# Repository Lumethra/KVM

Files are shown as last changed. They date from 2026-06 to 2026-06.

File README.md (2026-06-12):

# KVM
## What is this?

Its a KVM, just there is a catch, it should be a KM, because it doesnt fulfill the criterias for the "V". A KVM is a device that can let you switch the connected USB-devices from one PC to another, so just press or toggle the switch and your mouse and keyboard are connected to the other device, for example a laptop. KVM stands for Keyboard, Video, Mouse and since my thingi only supports USB-devices it only supports keyboards, mice and maybe other usb devices. Thats also why I would call it a KM. 

### Features:
  - 2 USB-C-upstreams
      - for the 2 PC's
  - 4 USB-downstreams
      - 2 USB-C
      - 2 USB-A
  - 1 SL2.1S to bundle the 4 downstreams into 2 pins (D+, D-)
  - 1 Mux to switch between the 2 upstreams for PC switching
  - 1 slider, toggle, switch kinda thingi to set the state

---

## Why?

I thought it would be funny to try that out. It turned out to be quite easy. I also thought about USB3.0 and even USB4.0, but that was too complicated and I settled on USB2.0. A KVM is also sth that you can use in your daily workflow and could turn out to be really handy. 

---

## How??

It was simply replicating the USB-Hub, which I made for my keebs and connecting the upstream to the mux which handles the switching between the 2 USB-C(2.0) to archieve the switching between devices. 

---

## Renders 
> enjoy the raytracing

| PCB with Components | 
| --- |
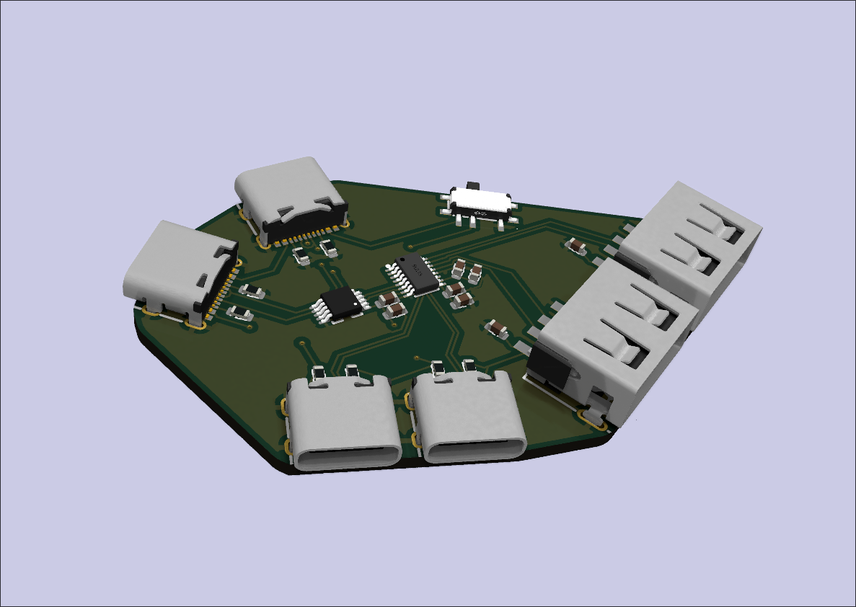
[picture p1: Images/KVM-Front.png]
KVM Front with Components
|  |
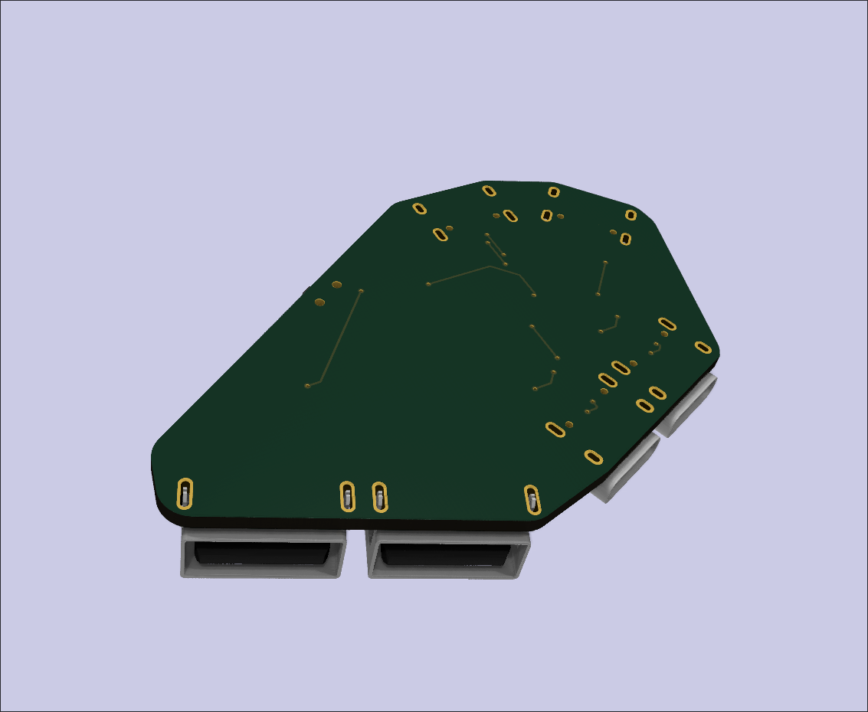
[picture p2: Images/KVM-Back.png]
KVM Back with Components
|  |

| PCB without Components |
| --- |
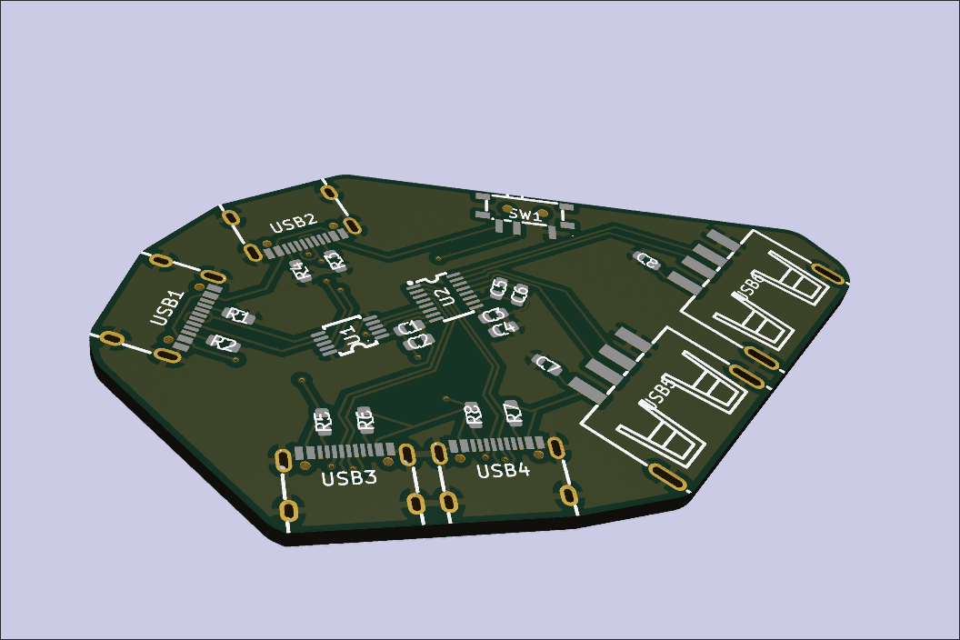
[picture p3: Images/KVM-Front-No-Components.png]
KVM Front without Components
|  |
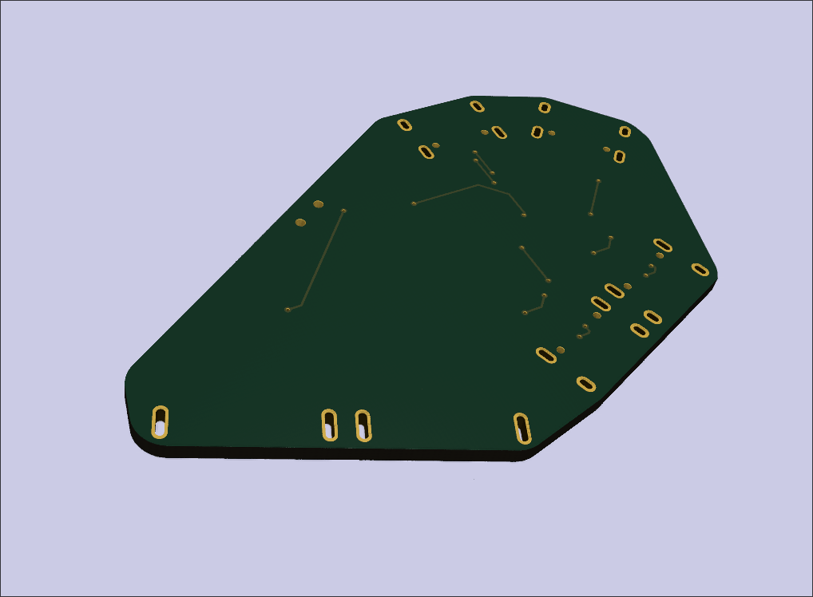
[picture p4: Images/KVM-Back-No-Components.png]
KVM Back without Compoenents
|  |

---

## PCB + Schematics

| Schematics |
| --- |
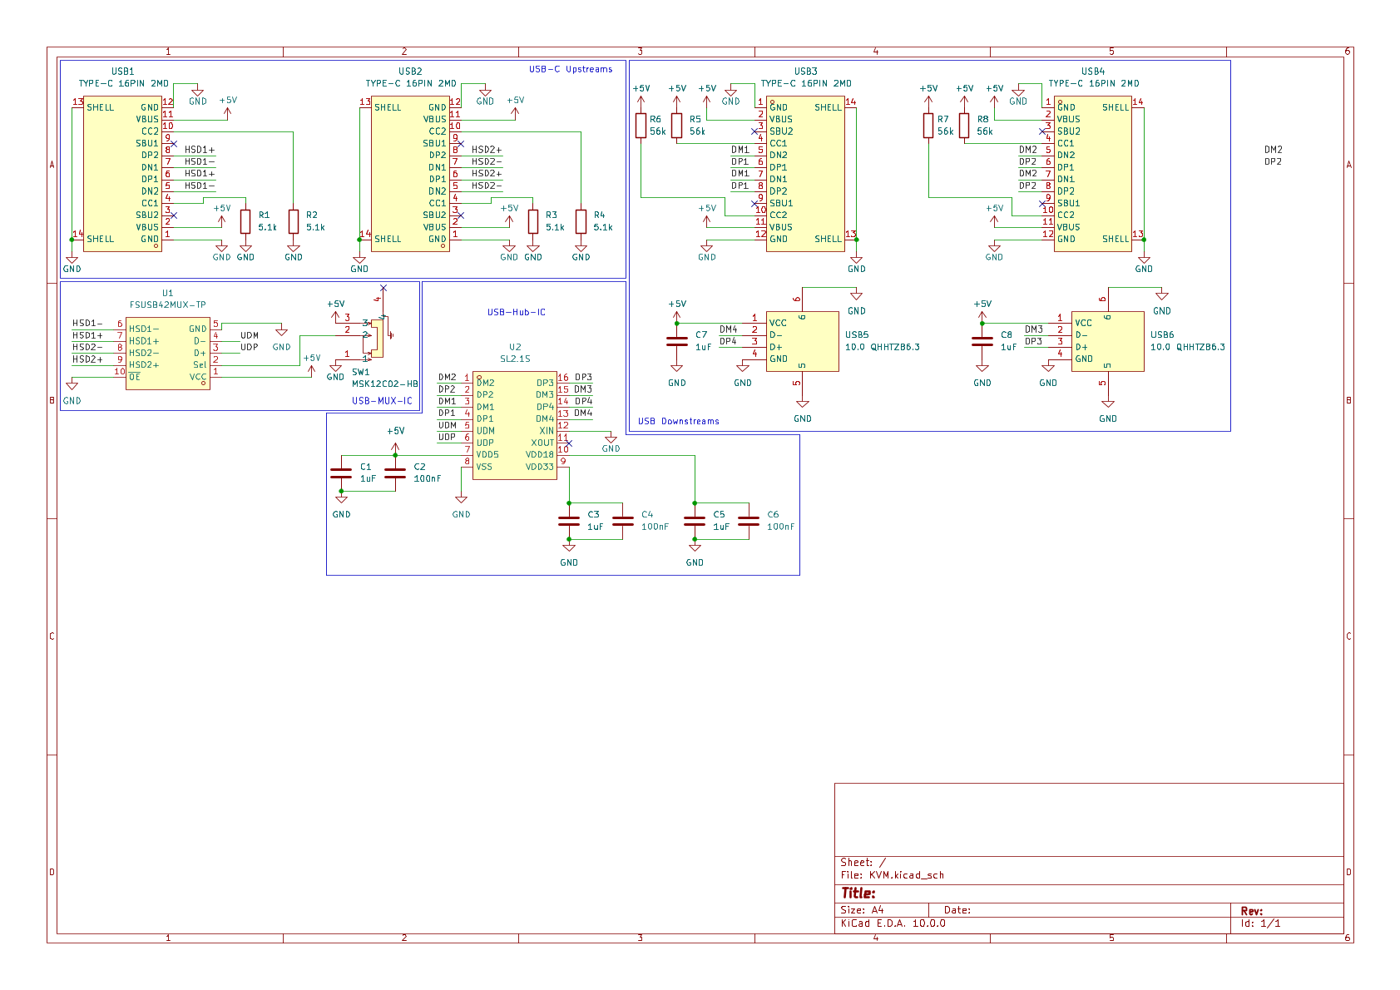
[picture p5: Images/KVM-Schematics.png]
KVM-PCB
|  |

| PCB |
| --- |
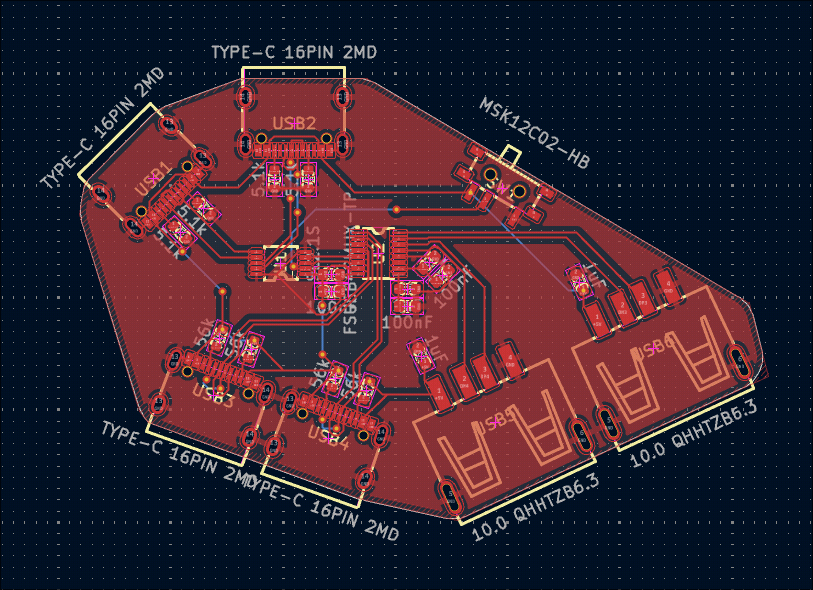
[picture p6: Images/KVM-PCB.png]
KVM-Schematics
|  |

---

<details>
  <summary>
    <h2>Zine</h2>
  </summary>

| Zine |
| --- |
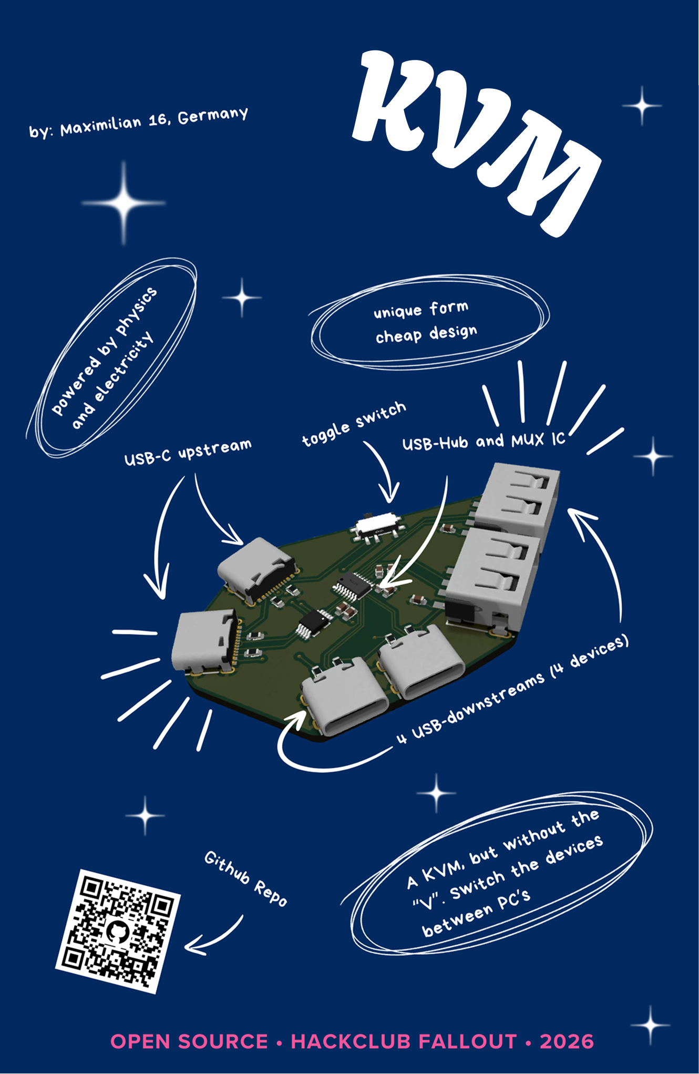
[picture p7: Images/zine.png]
KVM-Zine
|  |

  ---
</details>

## BOM

| Part | Purpose | Cost | Quantity | Total Cost | LCSC/JLCPCB Number | Link |
| --- | --- | --- | --- | --- | --- | --- |
| PCB |connect everything together | $2 | 1(5) | $2 | ~ | [JLCPCB](https://jlcpcb.com) |
| Capacitors | reduce noise in the power | $0.0032 | 8 | $0.0256 | C15849, C14663 | [C15849](https://jlcpcb.com/partdetail/C15849) / [C14663](https://jlcpcb.com/partdetail/C14663) |
| Resistors | prevent things go boom | $0.0016 | 8 | $0.0138 | C23186, C23206 | [C23186](https://jlcpcb.com/partdetail/C23186),[C23206](https://jlcpcb.com/partdetail/C23206) |
| Toggle Switch | say which computer | $0.0579 | 1 | $0.0579 | C431541 | [JLCPCB](https://jlcpcb.com/partdetail/C431541)  |
| USB Mux | change computer (USB) | $0.3720 | 1 | $0.3720 | C42407092 | [JLCPCB](https://jlcpcb.com/partdetail/C42407092)  |
| USB Hub | bundle the downstream | $0.2258 | 1 | $0.2258 | C2684433 | [JLCPCB](https://jlcpcb.com/partdetail/C2684433)  |
| UCB-C | usb connectors | $0.0740 | 4 | $0.2960 | C2765186 | [JLCPCB](https://jlcpcb.com/partdetail/C2765186)  |
| USB-A | usb connectors big | $0.0636 | 2 | $0.1272 | C668591 | [JLCPCB](https://jlcpcb.com/partdetail/C668591)  |

> the prices can change depending on the provider and time <br>
> you can find the JLCPCB parts on [LCSC](https://lcsc.com/) too (exept the PCB) <br>

---

## Contribute

Want to add something?? Want a real KVM with Video? Found any bugs?? Feel free to open a PR (pull request) or an issue. 
> the libraries are all imported with [easyeda2kicad](https://github.com/uPesy/easyeda2kicad.py)

---

## Thank you

A huge thank you to my brain, who didnt die in this session. Another huge thank you to all the guys teaching me hardware. A last thank you to my laptop and kicad who dont like each other and decides to crash alot.

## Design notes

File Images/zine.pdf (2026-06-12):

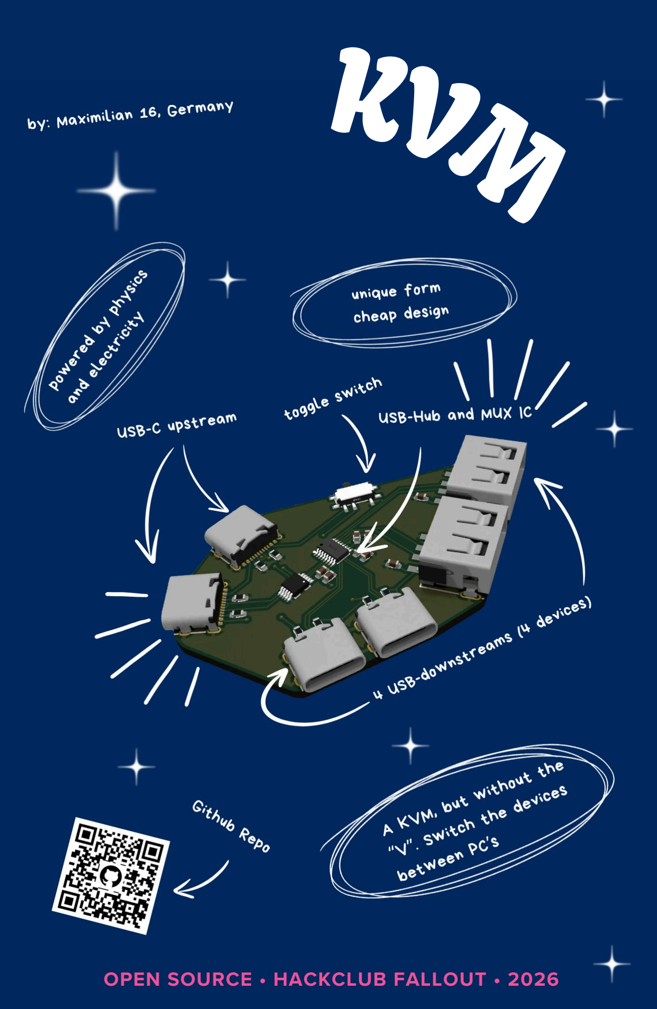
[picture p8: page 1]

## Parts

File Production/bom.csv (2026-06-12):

Name | Designator | Footprint | Quantity | Value | Price | LCSC Part # | Purchase Link
Capacitors 1uF | C1, C3, C5, C7, C8 | 0603 | 5 | 1uF | $0.0032 | C15849 | https://jlcpcb.com/partdetail/C15849
Capacitors 100nF | C2, C4, C6 | 0603 | 3 | 100nF | $0.0032 | C14663 | https://jlcpcb.com/partdetail/C14663
Resistors 5.1k | R1, R2, R3, R4 | 0603 | 4 | 5.1k | $0.0016 | C23186 | https://jlcpcb.com/partdetail/C23186
Resistors 56k | R5, R6, R7, R8 | 0603 | 4 | 56k | $0.0016 | C23206 | https://jlcpcb.com/partdetail/C23206
Toggle Switch | SW1 | SW-TH_MSK12C02-HB-1 | 1 | MSK12C02-HB | $0.0579 | C431541 | https://jlcpcb.com/partdetail/C431541
USB Mux | U1 | MSOP-10_L3.0-W3.0-P0.50-LS4.9-BL | 1 | FSUSB42MUX-TP | $0.3720 | C42407092 | https://jlcpcb.com/partdetail/C42407092
USB Hub | U2 | SSOP-16_L4.6-W2.6-P0.53-LS4.0-BL | 1 | SL2.1S | $0.2258 | C2684433 | https://jlcpcb.com/partdetail/C2684433
USB-C Connector | USB1, USB2, USB3, USB4 | USB-C-SMD_TYPE-C-6PIN-2MD-073 | 4 | TYPE-C 16PIN 2MD | $0.0740 | C2765186 | https://jlcpcb.com/partdetail/C2765186
USB-A Connector | USB5, USB6 | USB-A-TH_10.0QHHTZB6.3 | 2 | 10.0 QHHTZB6.3 | $0.0636 | C668591 | https://jlcpcb.com/partdetail/C668591

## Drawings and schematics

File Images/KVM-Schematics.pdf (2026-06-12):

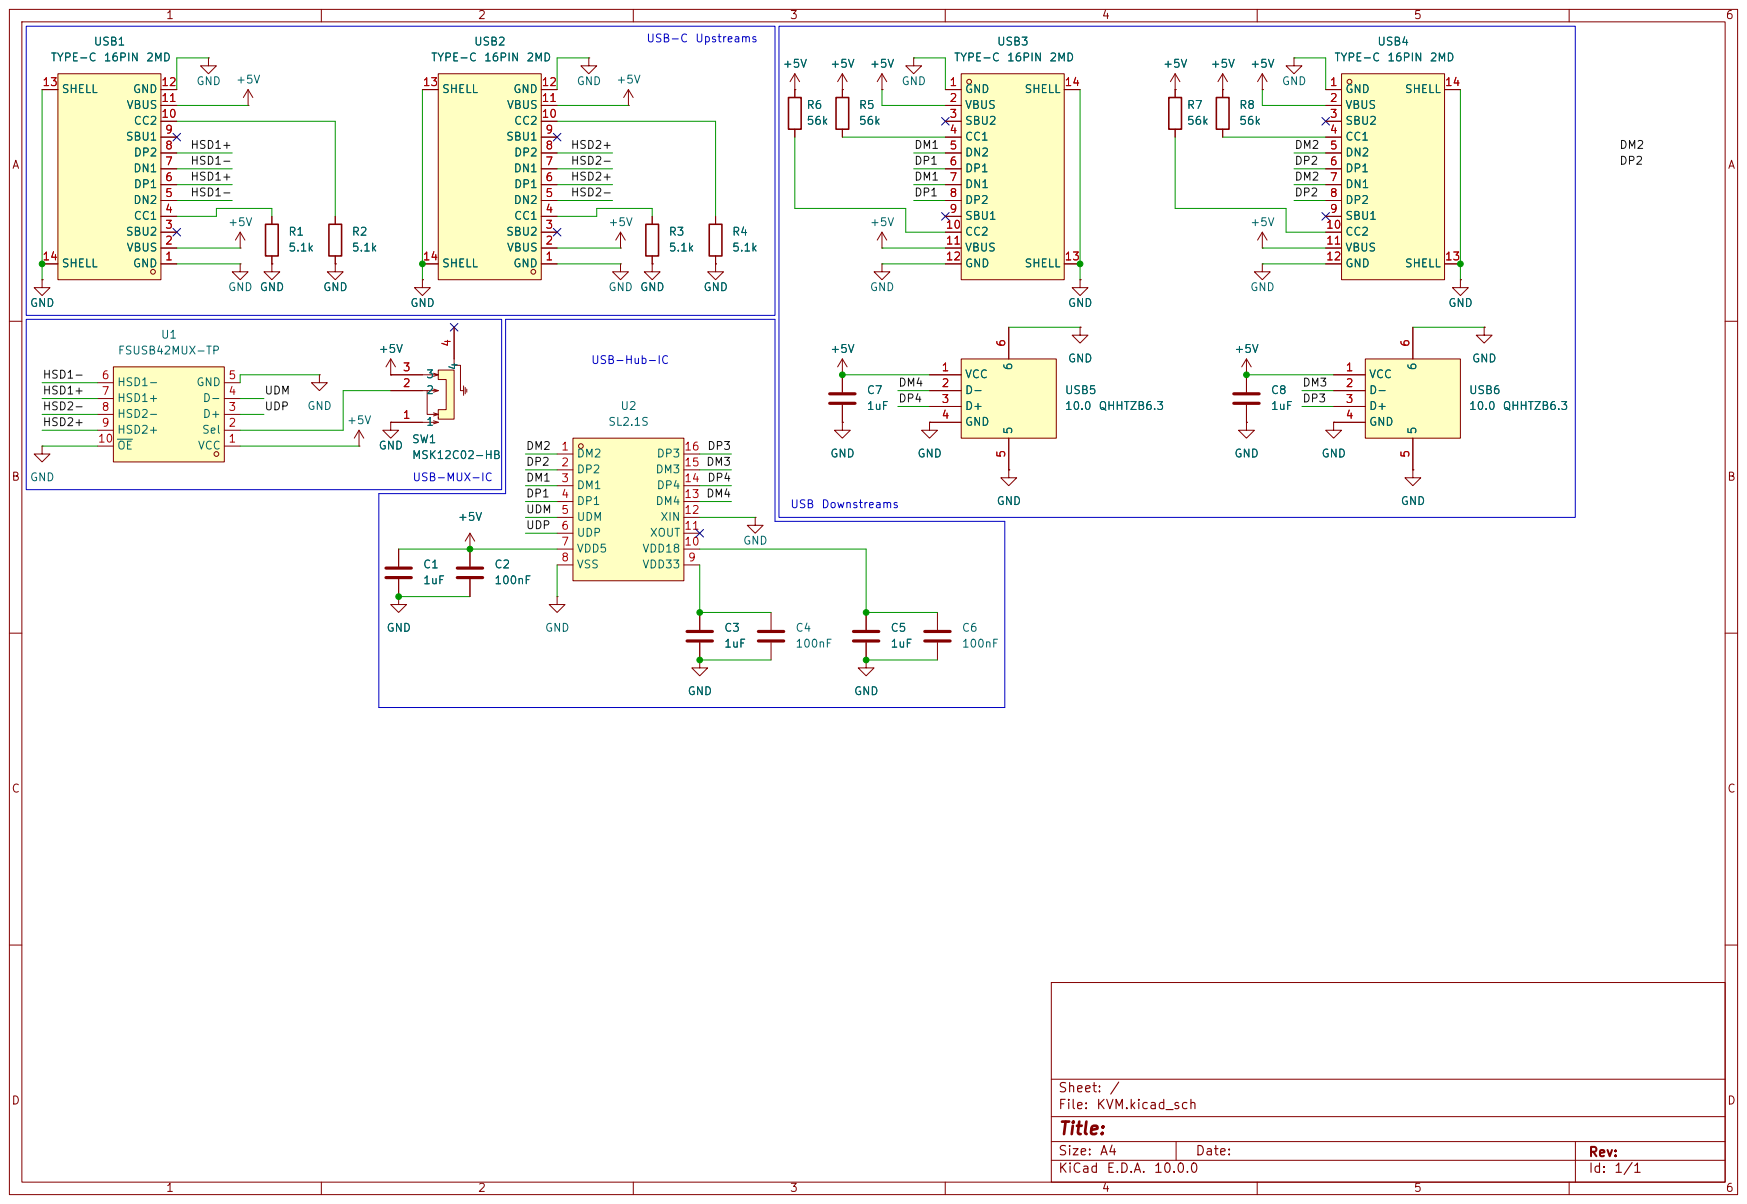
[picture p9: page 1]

Size: A4 | Rev:
KiCad E.D.A. 10.0.0 | Id: 1/1

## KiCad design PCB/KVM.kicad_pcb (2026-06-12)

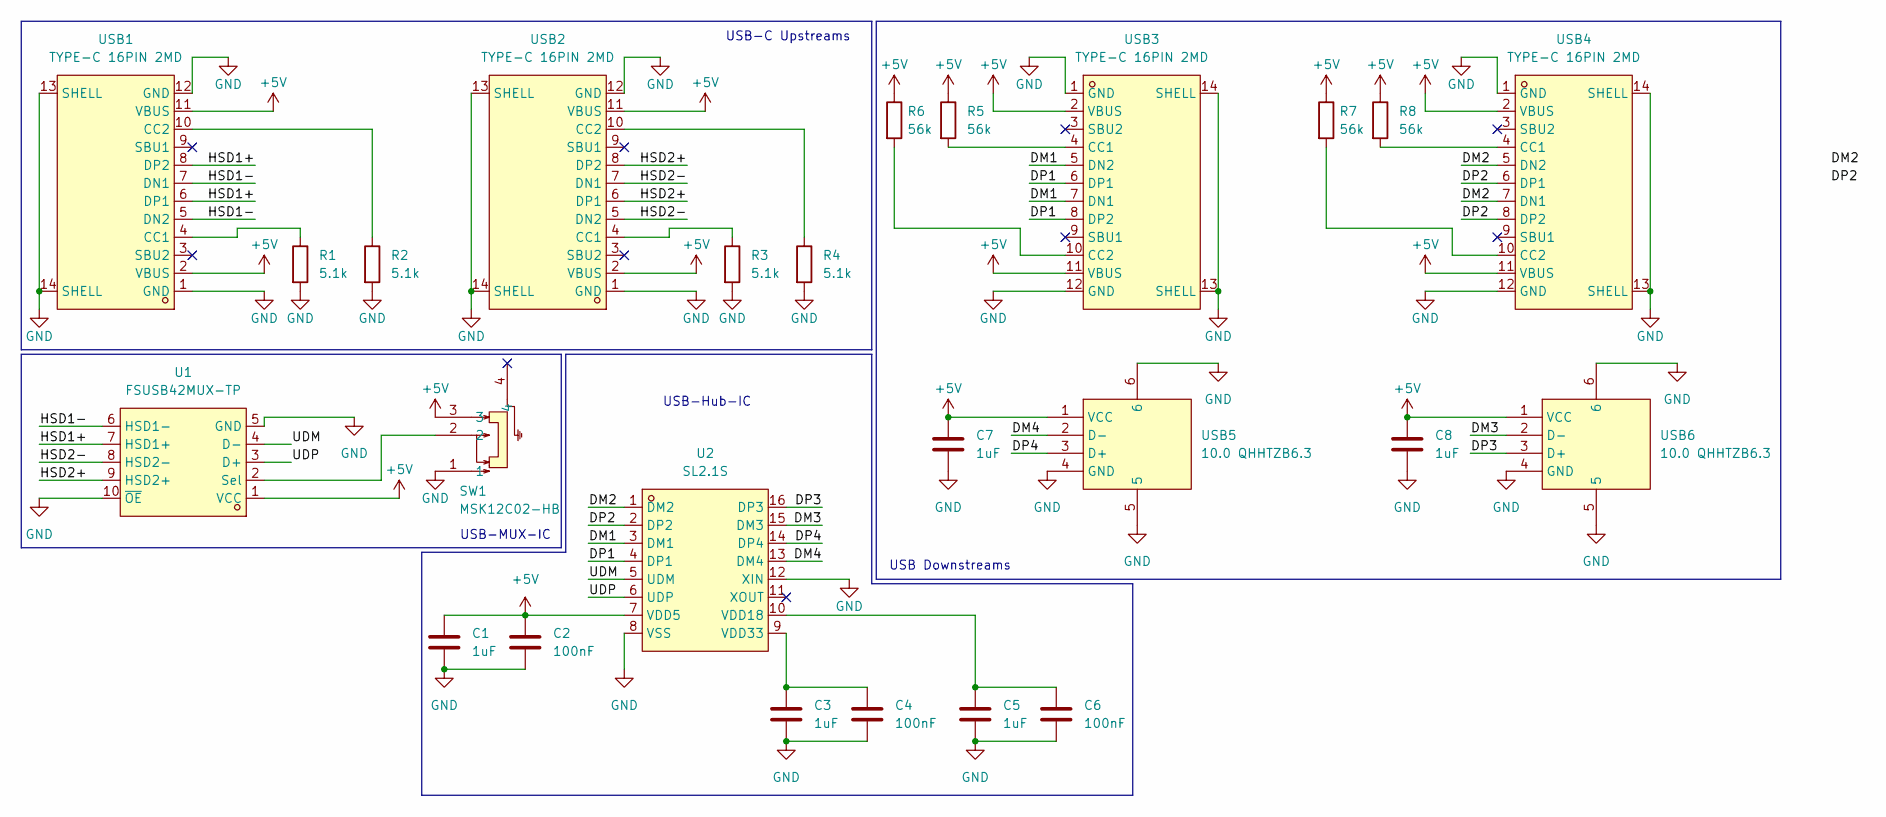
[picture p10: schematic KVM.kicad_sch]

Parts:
C1, C3, C5, C7, C8: 1uF; C_0603_1608Metric; LCSC Part C15849
C2, C4, C6: 100nF; C_0603_1608Metric; LCSC Part C14663
R1, R2, R3, R4: 5.1k; R_0603_1608Metric; LCSC Part C23186
R5, R6, R7, R8: 56k; R_0603_1608Metric; LCSC Part C23206
SW1: MSK12C02-HB; SW-TH_MSK12C02-HB-1; MPN MSK12C02-HB; LCSC Part C431541
U1: FSUSB42MUX-TP; MSOP-10_L3.0-W3.0-P0.50-LS4.9-BL; MPN FSUSB42MUX-TP; LCSC Part C42407092
U2: SL2.1S; SSOP-16_L4.6-W2.6-P0.53-LS4.0-BL; MPN SL2.1s; LCSC Part C2684433
USB1, USB2, USB3, USB4: TYPE-C 16PIN 2MD; USB-C-SMD_TYPE-C-6PIN-2MD-073; MPN TYPE-C 16PIN 2MD(073); LCSC Part C2765186
USB5, USB6: 10.0 QHHTZB6.3; USB-A-TH_10.0QHHTZB6.3; MPN 10.0 QHHTZB6.3; LCSC Part C668591

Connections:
+5V: C1.1, C2.1, C7.1, C8.1, R5.1, R6.1, R7.1, R8.1, SW1.3, U1.1 (VCC), U2.7 (VDD5), USB1.2 (VBUS), USB1.11 (VBUS), USB2.2 (VBUS), USB2.11 (VBUS), USB3.2 (VBUS), USB3.11 (VBUS), USB4.2 (VBUS), USB4.11 (VBUS), USB5.1 (VCC), USB6.1 (VCC)
/DM1: U2.3 (DM1), USB3.5 (DN2), USB3.7 (DN1)
/DM2: U2.1 (DM2), USB4.5 (DN2), USB4.7 (DN1)
/DM3: U2.15 (DM3), USB6.2 (D-)
/DM4: U2.13 (DM4), USB5.2 (D-)
/DP1: U2.4 (DP1), USB3.6 (DP1), USB3.8 (DP2)
/DP2: U2.2 (DP2), USB4.6 (DP1), USB4.8 (DP2)
/DP3: U2.16 (DP3), USB6.3 (D+)
/DP4: U2.14 (DP4), USB5.3 (D+)
/HSD1+: U1.7 (HSD1+), USB1.6 (DP1), USB1.8 (DP2)
/HSD1-: U1.6 (HSD1-), USB1.5 (DN2), USB1.7 (DN1)
/HSD2+: U1.9 (HSD2+), USB2.6 (DP1), USB2.8 (DP2)
/HSD2-: U1.8 (HSD2-), USB2.5 (DN2), USB2.7 (DN1)
/UDM: U1.4 (D-), U2.5 (UDM)
/UDP: U1.3 (D+), U2.6 (UDP)
GND: C1.2, C2.2, C3.2, C4.2, C5.2, C6.2, C7.2, C8.2, R1.2, R2.2, R3.2, R4.2, SW1.1, U1.5 (GND), U1.10 (~OE), U2.8 (VSS), U2.12 (XIN), USB1.1 (GND), USB1.12 (GND), USB1.13 (SHELL), USB1.14 (SHELL), USB2.1 (GND), USB2.12 (GND), USB2.13 (SHELL), USB2.14 (SHELL), USB3.1 (GND), USB3.12 (GND), USB3.13 (SHELL), USB3.14 (SHELL), USB4.1 (GND), USB4.12 (GND), USB4.13 (SHELL), USB4.14 (SHELL), USB5.4 (GND), USB5.5, USB5.6, USB6.4 (GND), USB6.5, USB6.6
unnamed: SW1.2, U1.2 (Sel)
unnamed: C5.1, C6.1, U2.10 (VDD18)
unnamed: C3.1, C4.1, U2.9 (VDD33)
unnamed: R1.1, USB1.4 (CC1)
unnamed: R2.1, USB1.10 (CC2)
unnamed: R3.1, USB2.4 (CC1)
unnamed: R4.1, USB2.10 (CC2)
unnamed: R5.2, USB3.4 (CC1)
unnamed: R6.2, USB3.10 (CC2)
unnamed: R8.2, USB4.4 (CC1)
unnamed: R7.2, USB4.10 (CC2)

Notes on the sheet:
USB-MUX-IC
USB-Hub-IC
USB-C Upstreams
USB Downstreams

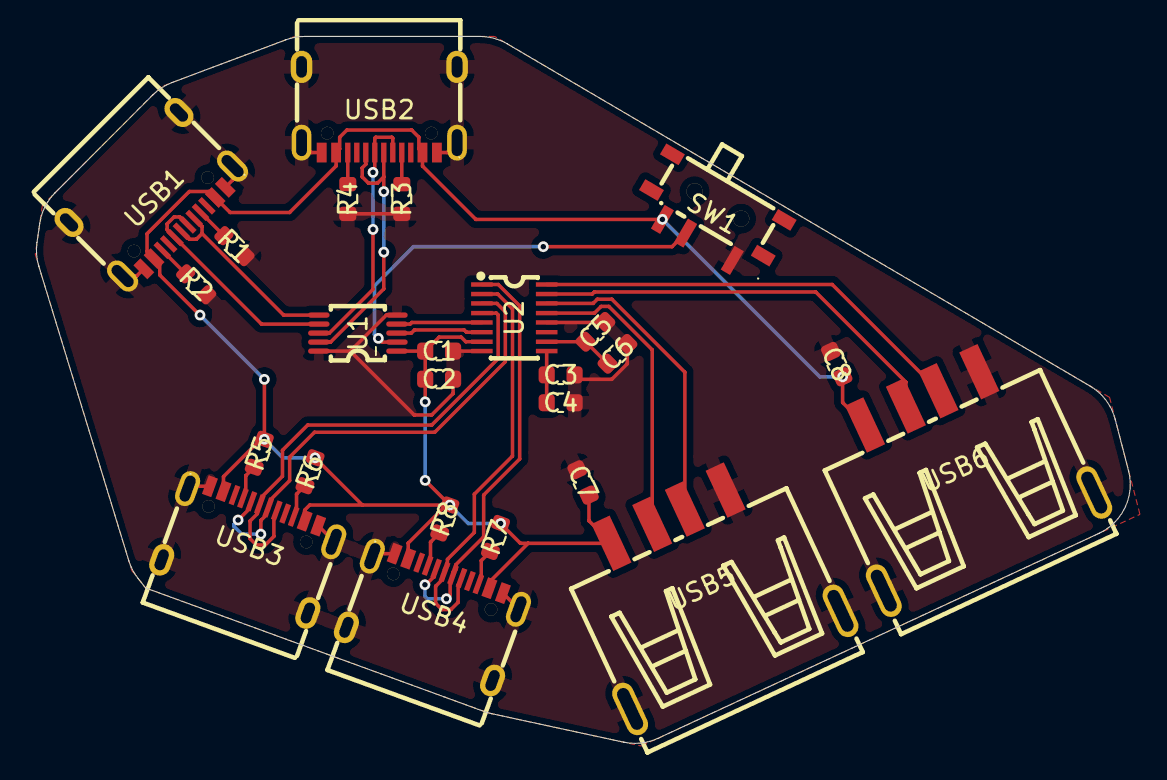
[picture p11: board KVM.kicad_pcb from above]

Board: 2 copper layers, 60.8 x 39.3 mm, 25 parts (0 on the bottom side), 27 nets.
